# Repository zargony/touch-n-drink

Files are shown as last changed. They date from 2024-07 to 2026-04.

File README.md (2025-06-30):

# Touch 'n Drink

Touch 'n Drink is a small device that reads NFC id cards of club members of the [Aeroclub (LSC) Hamm][LSC Hamm] and allows to pay for items like cold drinks offered at the clubhouse. Purchases are forwarded to accounting so members pay via their regular monthly invoices. We're located at airfield [EDLH] in Hamm, Germany.

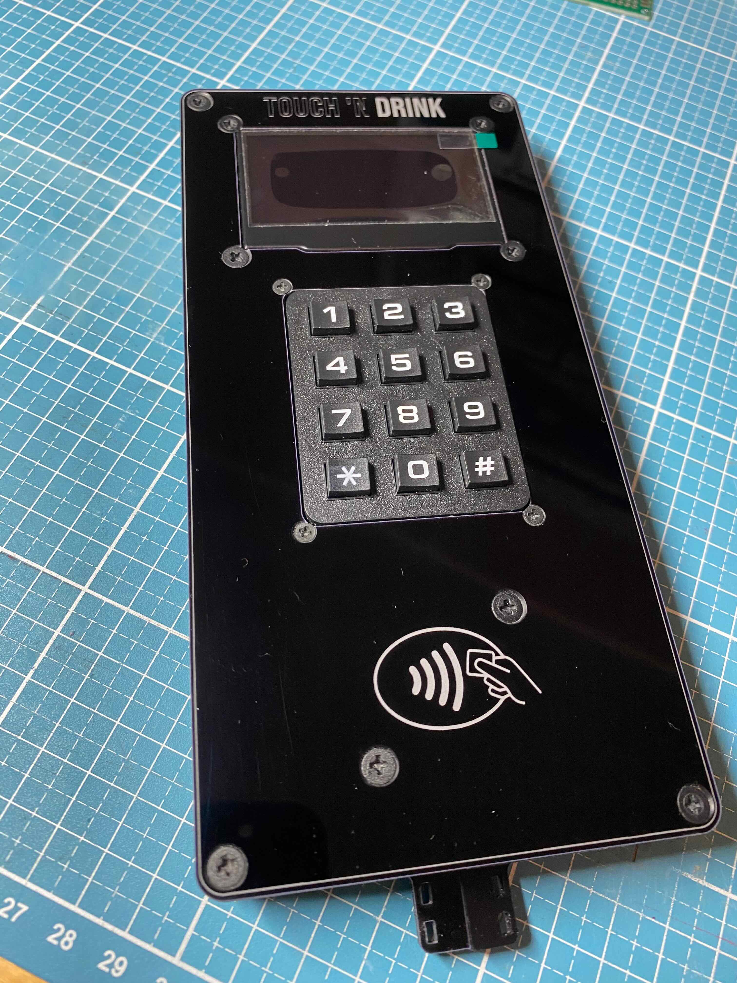
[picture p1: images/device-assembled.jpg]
Assembled device


## Features

- Fetches authorized users and list of articles for sale from [Vereinsflieger] API
- Allows users to identify with NFC tag or id card and purchase articles
- Optional event tracking using [Mixpanel] for usage analytics
- Connects to 2.4 GHz WPA2/WPA3 Wifi (IPv4, DHCP)
- Simple numeric keypad and large, bright OLED display
- Power supply using standard USB-C cable (PD not required)
- Ergonomically priced and widely available hardware components
- Magnetic wall mount

## Hardware

ESP32-C3, Keypad, OLED Display and NFC reader in a custom acrylic case. See [hardware] folder for details.

## PCB

Small custom PCB for the microcontroller and connectors to other components. Either manufactured or manually soldered to a perfboard. See [pcb] folder for details.

## Firmware

Written in [Rust]. See [firmware] folder for details.

## Contributions

If you like this project, want to use it at your club, or if you want to discuss ideas and suggestions, feel free to start a [discussion][discussions] or open an [issue][issues]. Feel free to fork this repository and base your work upon it. Please open a pull request if your changes or features are useful to a broad audience.

## License

Hardware licensed under the [CERN Open Hardware License (Strongly Reciprocal)][OHL]. Software licensed under the [European Union Public License (EUPL)][EUPL]. Unless you explicitly state otherwise, any contribution intentionally submitted for inclusion in the work by you, shall be licensed as above, without any additional terms or conditions.

[hardware]: ./hardware
[firmware]: ./firmware
[pcb]: ./pcb

[discussions]: https://github.com/zargony/touch-n-drink/discussions
[issues]: https://github.com/zargony/touch-n-drink/issues

[EDLH]: https://skyvector.com/airport/EDLH/Hamm-Lippewiesen-Airport
[EUPL]: https://interoperable-europe.ec.europa.eu/collection/eupl/eupl-text-eupl-12
[LSC Hamm]: https://flugplatz-hamm.de
[Mixpanel]: https://mixpanel.com
[OHL]: https://cern-ohl.web.cern.ch/home
[Rust]: https://www.rust-lang.org
[Vereinsflieger]: https://www.vereinsflieger.de

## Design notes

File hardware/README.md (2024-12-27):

# Touch 'n Drink Hardware

Assembled device:

Assembled device

## Electronics

Wiring of parts (PCB version):

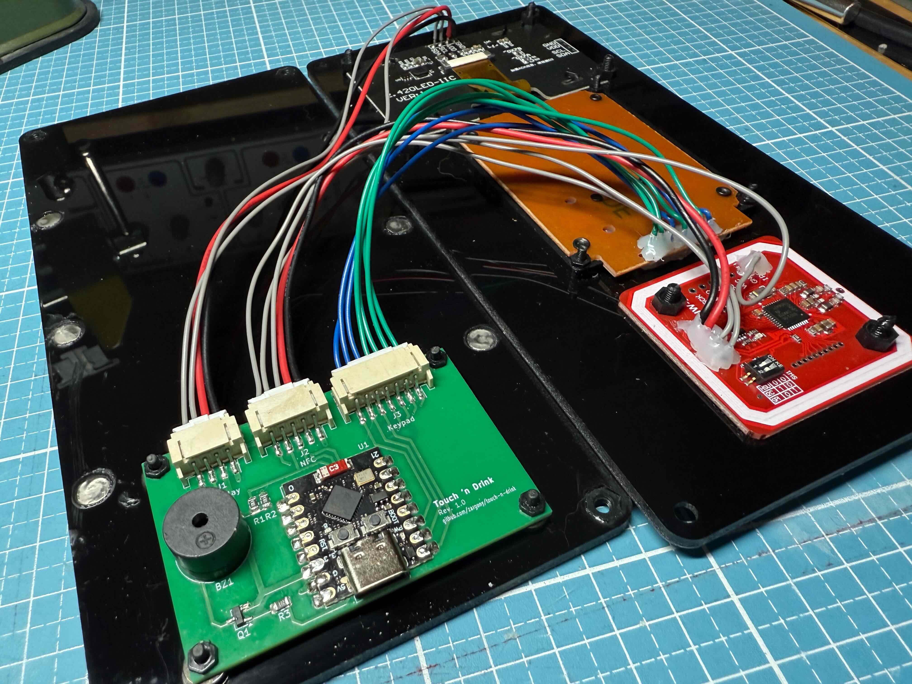
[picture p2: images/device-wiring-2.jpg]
Wiring of parts with PCB


Wiring of parts (perfboard version):

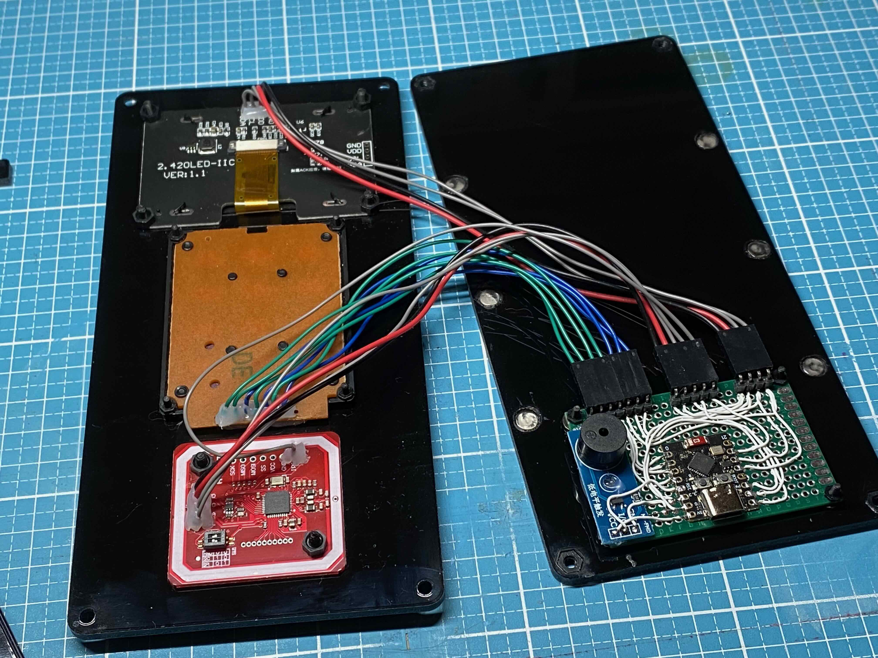
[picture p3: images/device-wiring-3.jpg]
Wiring of parts with perfboard


JST-PH connectors:

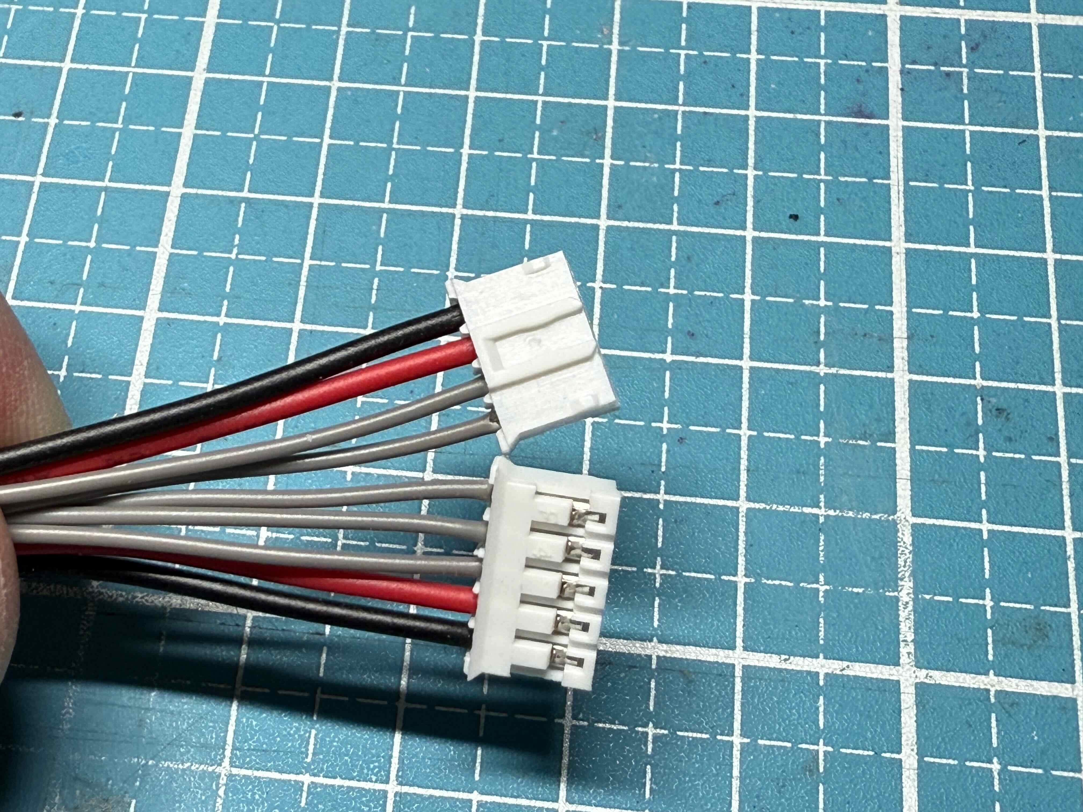
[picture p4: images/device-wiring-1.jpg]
JST-PH connectors


Prototype breadboard:

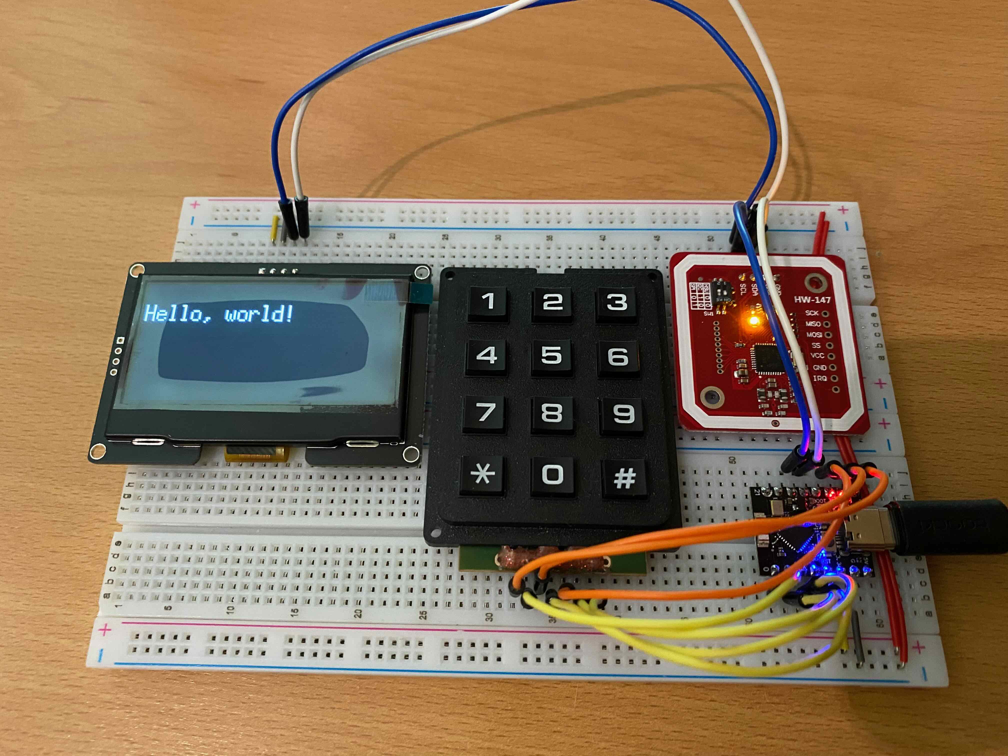
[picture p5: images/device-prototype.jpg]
Prototype breadboard


### Electronic Parts

- OLED display 2.42" I2C
  ([AliExpress](https://s.click.aliexpress.com/e/_DCysL8J)) <!-- https://www.aliexpress.com/item/1005006100836064.html -->
  ([Amazon](https://amzn.to/460m6Js)) <!-- https://www.amazon.de/module-128x64-driver-SSD1309-interface/dp/B0C745HXGB -->
  ([Model](https://grabcad.com/library/display-oled-2-42-1))
- Matrix 4x3 keypad
  ([AliExpress](https://s.click.aliexpress.com/e/_DEhcWpV)) <!-- https://www.aliexpress.com/item/1005005536316575.html -->
  ([Amazon](https://amzn.to/3Y1Twpa)) <!-- https://www.amazon.de/HALJIA-Tastatur-Membran-kompatibel-Arduino/dp/B08BBXH6NM -->
  ([Model](https://grabcad.com/library/keypad-3x4-w-pcb-1))
- PN532 NFC module v3
  ([AliExpress](https://s.click.aliexpress.com/e/_DFyKykT)) <!-- https://www.aliexpress.com/item/1005005973913526.html -->
  ([Amazon](https://amzn.to/3S3gAjo)) <!-- https://www.amazon.de/Diyeeni-Funkmodul-Reader-Android-Communication-default/dp/B07V5QDMR4 -->
  ([Model](https://grabcad.com/library/pn532-nfc-rfid-module-v3-kits-1))
- [PCB or perfboard](../pcb) with ESP32-C3

## Case

Lasercut acrylic sheets:

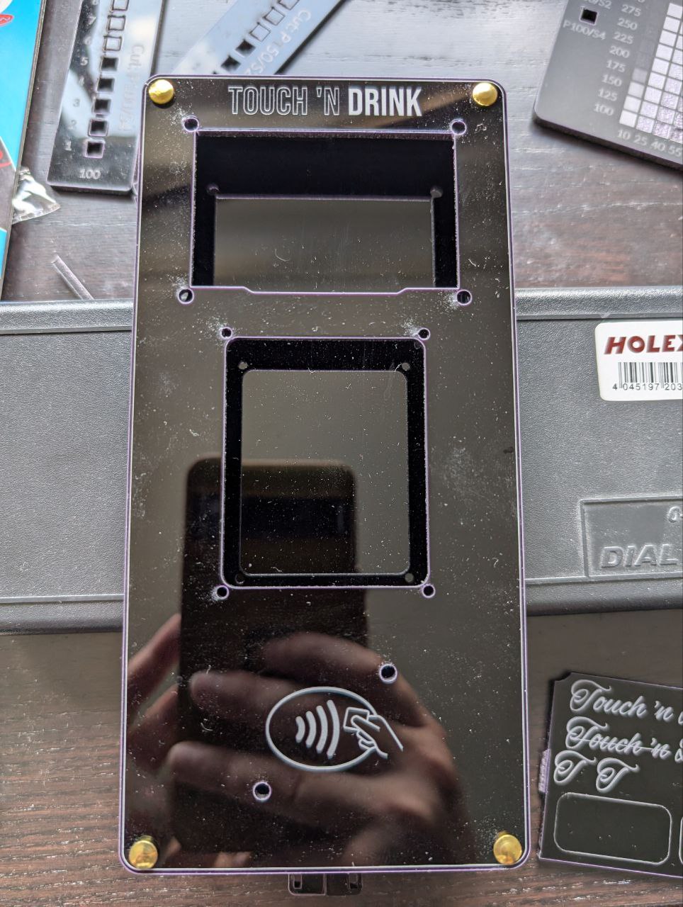
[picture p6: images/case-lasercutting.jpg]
Case lasercutting


Prototype cardboard case:

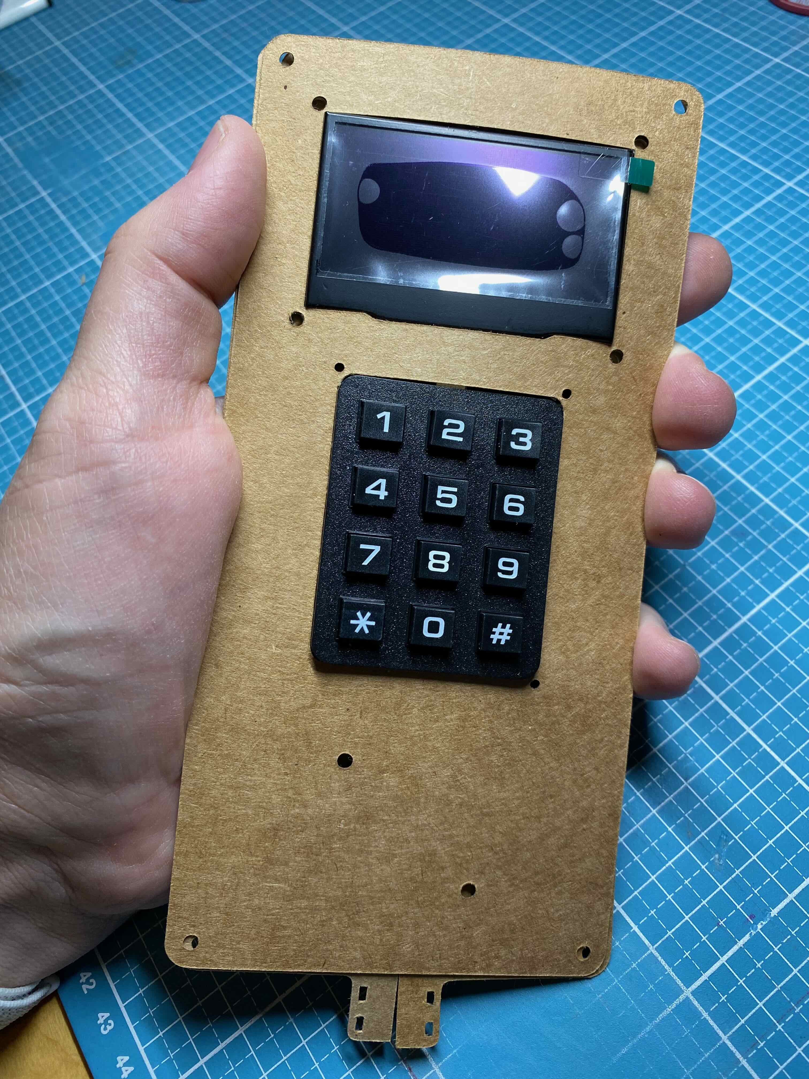
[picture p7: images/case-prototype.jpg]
Case paper prototype


Rendered CAD model:

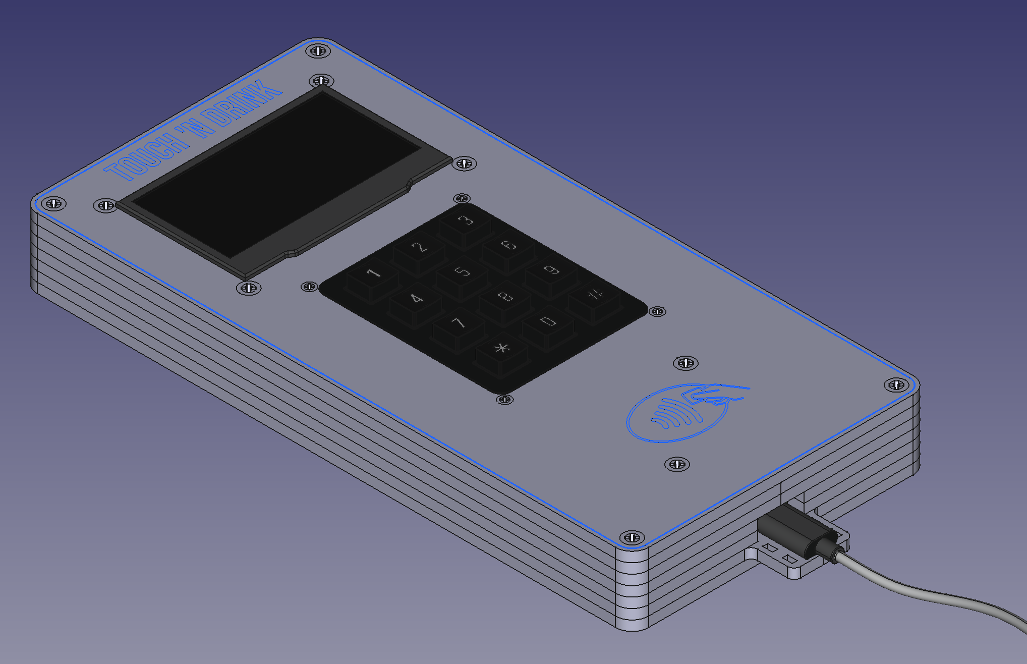
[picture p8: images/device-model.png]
Case rendered CAD model


### Hardware Parts

- Acrylic sheets, 3mm
- 8x M2x10 screws, countersunk, Nylon
  ([AliExpress](https://s.click.aliexpress.com/e/_Dnqr099)) <!-- https://www.aliexpress.com/item/1005006947644936.html -->
  ([Amazon](https://amzn.to/4bAfO4o)) <!-- https://www.amazon.de/CONPHERON-Kreuzschlitz-Senkschrauben-Kunststoff-Maschinenschrauben/dp/B09NXRQFHX -->
  ([Model](https://wiki.freecad.org/Fasteners_Workbench))
- 6x M3x10 screws, countersunk, Nylon
  ([AliExpress](https://s.click.aliexpress.com/e/_Dnqr099)) <!-- https://www.aliexpress.com/item/1005006947644936.html -->
  ([Amazon](https://amzn.to/4bAfO4o)) <!-- https://www.amazon.de/CONPHERON-Kreuzschlitz-Senkschrauben-Kunststoff-Maschinenschrauben/dp/B09NXRQFHX -->
  ([Model](https://wiki.freecad.org/Fasteners_Workbench))
- 6x M3x20 screws, countersunk, Nylon
  ([AliExpress](https://s.click.aliexpress.com/e/_Dnqr099)) <!-- https://www.aliexpress.com/item/1005006947644936.html -->
  ([Amazon](https://amzn.to/4bAfO4o)) <!-- https://www.amazon.de/CONPHERON-Kreuzschlitz-Senkschrauben-Kunststoff-Maschinenschrauben/dp/B09NXRQFHX -->
  ([Model](https://wiki.freecad.org/Fasteners_Workbench))
- 8x M2 nuts, Nylon
  ([AliExpress](https://s.click.aliexpress.com/e/_DEIu5LN)) <!-- https://www.aliexpress.com/item/1005004307521473.html -->
  ([Amazon](https://amzn.to/4603OYy)) <!-- https://www.amazon.de/CONPHERON-Kunststoff-Sechskant-Schwarz-Sechskantmutter/dp/B09N1HN8QR -->
  ([Model](https://wiki.freecad.org/Fasteners_Workbench))
- 12x M3 nuts, Nylon
  ([AliExpress](https://s.click.aliexpress.com/e/_DEIu5LN)) <!-- https://www.aliexpress.com/item/1005004307521473.html -->
  ([Amazon](https://amzn.to/4603OYy)) <!-- https://www.amazon.de/CONPHERON-Kunststoff-Sechskant-Schwarz-Sechskantmutter/dp/B09N1HN8QR -->
  ([Model](https://wiki.freecad.org/Fasteners_Workbench))
- 12x 6x3 mm Neodymium magnets (optional)
  ([AliExpress](https://s.click.aliexpress.com/e/_Dkv50zJ)) <!-- https://www.aliexpress.com/item/1005001529831924.html -->
  ([Amazon](https://amzn.to/3BZGW0k)) <!-- https://www.amazon.de/Magnete-K%C3%BChlschrankmagnete-Whiteboard-Magnettafel-Handwerk/dp/B09W8R43Q8 -->
- USB-C cable
  ([Model](https://grabcad.com/library/usb-c-with-flexed-cable-1))

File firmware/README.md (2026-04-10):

# Touch 'n Drink Firmware

Firmware images are automatically build by GitHub actions. They can be downloaded from the [releases] page and flashed to a microcontroller [from your browser][esptool-js]. The setup described below is only needed for local development.

## Requirements

For local development, you need a [Rust] toolchain. If your OS doesn't already provide it, easiest way to install and manage Rust toolchains is to use [rustup], or use the official Docker image `rust:1`.

The Rust toolchain needs to support cross-compiling to the microcontroller's target architecture. If you're using `rustup`, it'll automatically download the required components as specified in `rust-toolchain.toml`.

To flash the firmware to a device, the `espflash` and `cargo-espflash` tools can be used. They integrate well with Rust build tools and can be installed with `cargo install espflash cargo-espflash`.

## Building the Firmware

To build the firmware using the debug profile, use:

```sh
cargo xtask build
```

This will run `cargo build` with options to build a firmware image for the microcontroller. It'll then use `espflash save-image` to produce OTA and factory images (.bin files) that can be flashed to the microcontroller.

## Flash Firmware to Device

To build the firmware using the debug profile and flash it to a device, connect the device via its USB-C serial port and use:

```sh
cargo xtask run
```

This will build the firmware image and use `espflash` to flash the produced image to the microcontroller. It then resets the device and monitors any log output.

## Flash Configuration to Device

Configuration is stored in a separate flash partition and is therefore unaffected by firmware updates. As there is currently no way to change the configuration at runtime, it needs to be flashed to the device manually (once).

Create a custom configuration, e.g. `config.json`. See `config-example.json` for available settings. Before flashing, keep it small and remove all comments, either manually or by using the `jq` tool:

```sh
jq -c < config.json > config.min.json
```

Store the minimized configuration to the device's `config` partition using `espflash`:

```sh
espflash write-bin 0xd000 config.min.json
```

## Contributions

If you implement changes or features that can be useful for everyone, please fork this repository and open a pull request. Make sure to also update documentation and code comments accordingly and add a high level description of your changes to the changelog. Also make sure that all CI jobs are passing and ideally try flashing and using the firmware image artifact to verify its behaviour.

[actions]: https://github.com/zargony/touch-n-drink/actions
[releases]: https://github.com/zargony/touch-n-drink/releases

[esptool-js]: https://espressif.github.io/esptool-js
[Rust]: https://www.rust-lang.org
[rustup]: https://rustup.rs

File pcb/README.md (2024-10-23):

# Touch 'n Drink PCB

## Custom PCB

A custom PCB holds the ESP32-C3 Module, a buzzer and connectors to wire up display, keypad and NFC reader. The PCB is quite simple and easy to manufacture. Choose any manufacturer you like.

If you don't want to manufacture a PCB, it's also easily possible to wire up components on a perfboard (see below).

Soldered PCB:

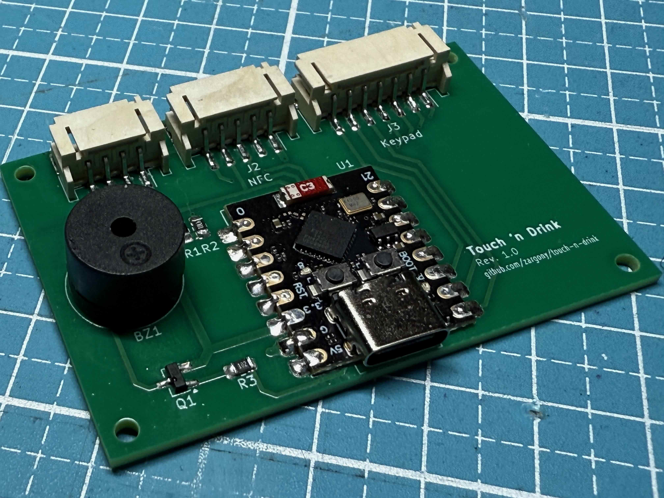
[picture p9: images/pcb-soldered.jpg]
Soldered PCB


Empty PCB:

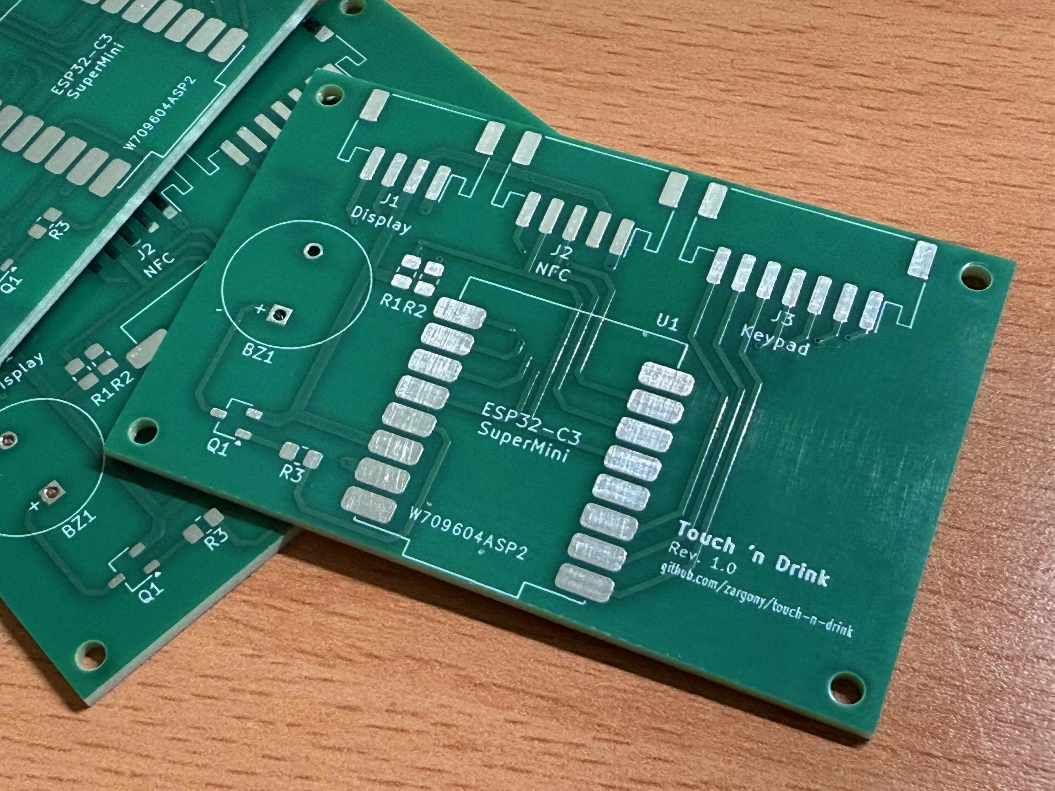
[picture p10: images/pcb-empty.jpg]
Empty PCB


Rendered PCB model:

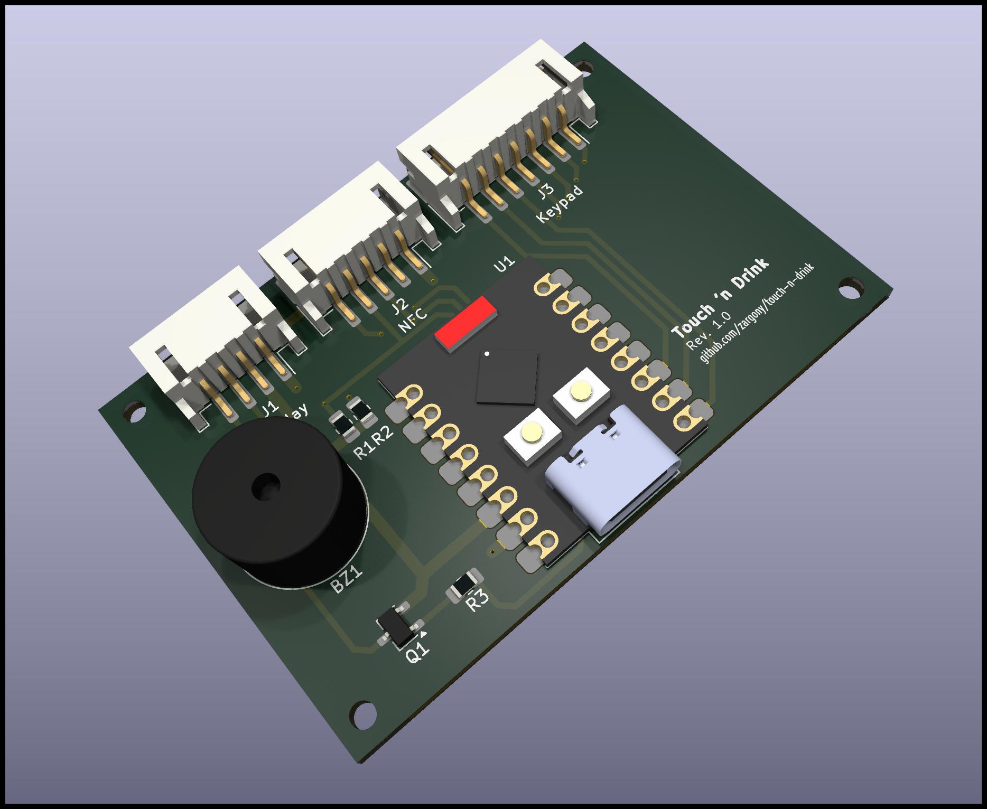
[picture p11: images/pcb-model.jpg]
Rendered PCB model


PCB Layout:

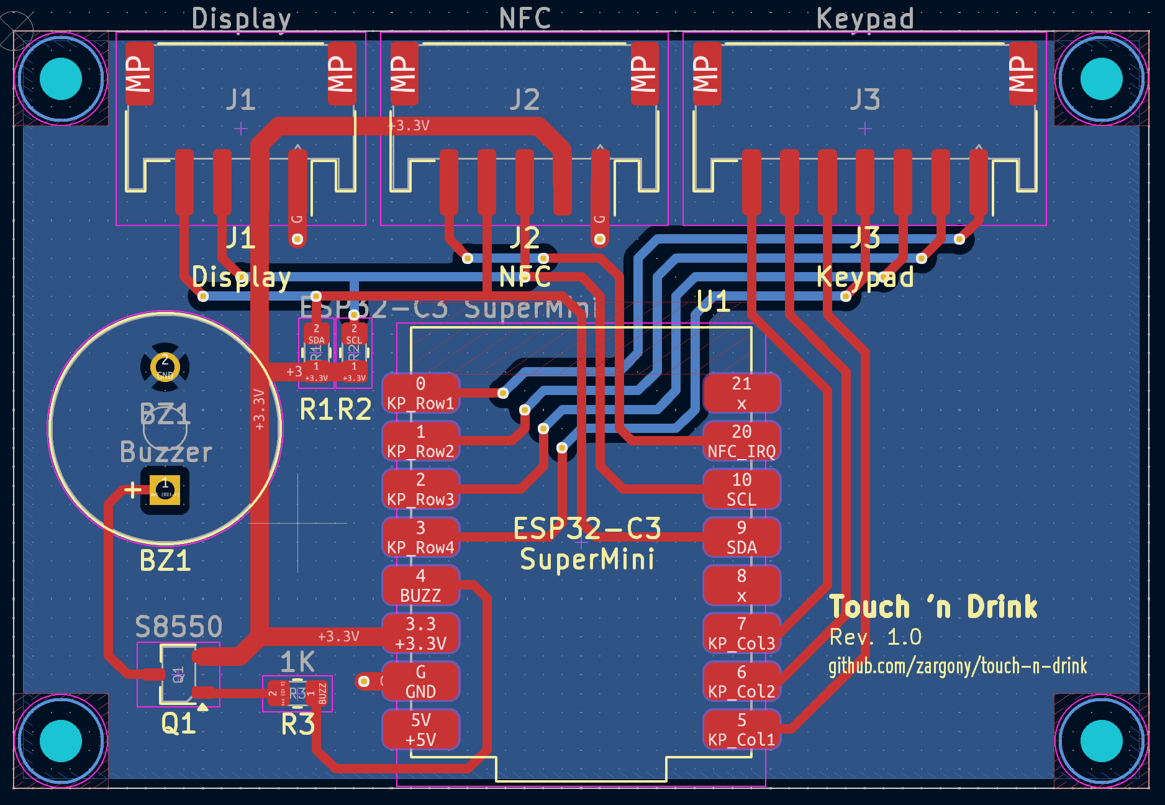
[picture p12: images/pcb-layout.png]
PCB layout


### Components

- 60x40 mm custom 2-layer PCB
- 1x ESP32-C3 SuperMini
  ([AliExpress](https://s.click.aliexpress.com/e/_DdYM4t9)) <!-- https://www.aliexpress.com/item/1005005967641936.html -->
  ([Amazon](https://amzn.to/4bCXYxz)) <!-- https://www.amazon.de/iHaospace-ESP32-C3-Mini-Entwicklungboard-ESP32-C3FN4/dp/B0D1Y5CPLX -->
  ([Model](https://grabcad.com/library/esp32c3-supermini-1))
- 1x Passive buzzer, THT, 12085
- 1x S8550, SMT, TSOT-23 (or other generic NPN transistor, BEC pin ordering)
- 1x 1k resistor, SMT, 0805
- 2x 5k resistor, SMT, 0805
- 1x 4-pin JST PH header, SMT, horizontal, S4B-PH-SM4-TB
- 1x 5-pin JST PH header, SMT, horizontal, S5B-PH-SM4-TB
- 1x 7-pin JST PH header, SMT, horizontal, S7B-PH-SM4-TB

## Perfboard (optional, instead of PCB)

Instead of manufacturing a custom PCB, you can wire up components on a 60x40 mm perfboard.

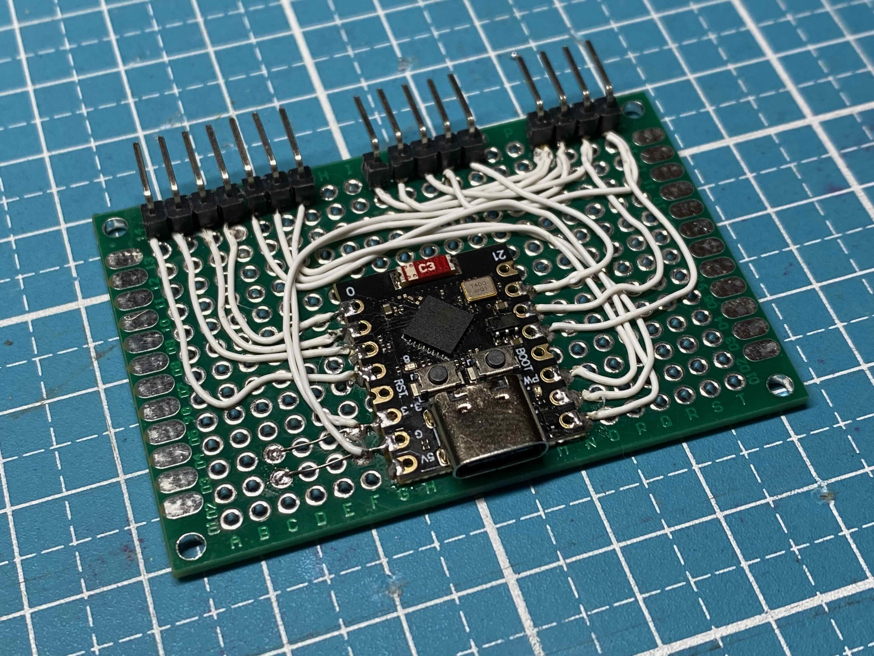
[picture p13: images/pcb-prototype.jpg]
Perfboard wiring


### Components

- Prototype PCB 60x40
  ([AliExpress](https://s.click.aliexpress.com/e/_Ddm12Wr)) <!-- https://www.aliexpress.com/item/1005006665029598.html -->
  ([Amazon](https://amzn.to/4eYnoIY)) <!-- https://www.amazon.de/Akozon-Leiterplatte-Doppelseiten-Prototyping-Universal/dp/B0B3MJ3WJM -->
  ([Model](https://grabcad.com/library/pcb-prototype-60x40-1))
- ESP32-C3 SuperMini
  ([AliExpress](https://s.click.aliexpress.com/e/_DdYM4t9)) <!-- https://www.aliexpress.com/item/1005005967641936.html -->
  ([Amazon](https://amzn.to/4bCXYxz)) <!-- https://www.amazon.de/iHaospace-ESP32-C3-Mini-Entwicklungboard-ESP32-C3FN4/dp/B0D1Y5CPLX -->
  ([Model](https://grabcad.com/library/esp32c3-supermini-1))
- Passive buzzer module, 3.3V, active low
  ([AliExpress](https://s.click.aliexpress.com/e/_Dl2FWF1)) <!-- https://www.aliexpress.com/item/1005006316591026.html -->
  ([Amazon](https://amzn.to/3Y72Ibw)) <!-- https://www.amazon.de/Jopto-Passives-niedrigstufiges-Lautsprecher-Kompatibel/dp/B096ZWCG7F -->
  ([Model](https://grabcad.com/library/buzzer-module-fc-07-1))
- Connectors for wiring to front panel (optional)
- Wires for soldering

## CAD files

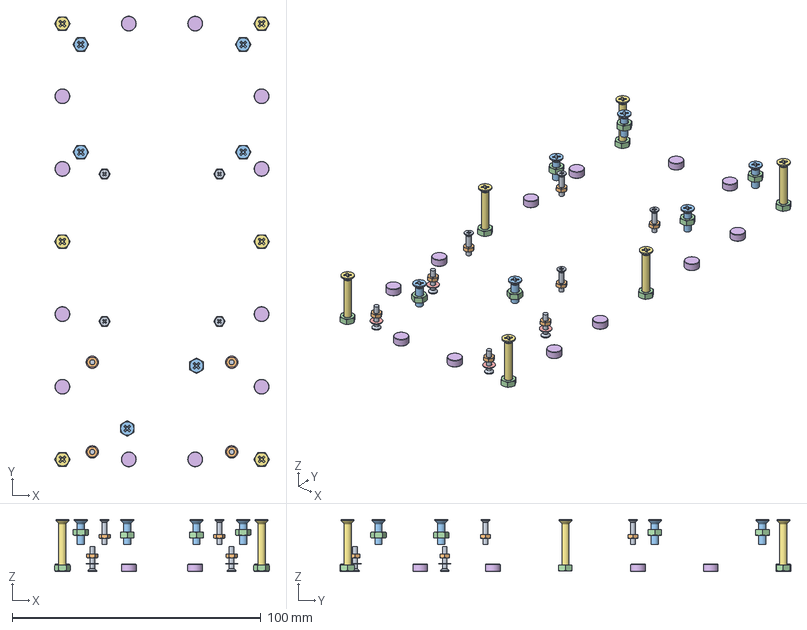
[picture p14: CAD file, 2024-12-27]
hardware/assembly.FCStd
86.4 x 181.0 x 21.0 mm
M2x10-Screw x 8
M2-Nut x 8
M3x10-Screw x 6
M3-Nut x 12
M2-Washer x 4
M3x20-Screw x 6

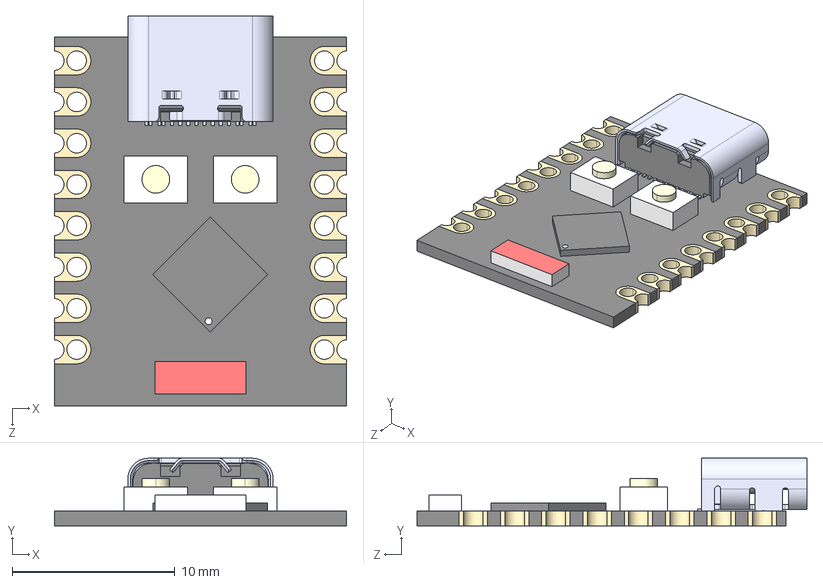
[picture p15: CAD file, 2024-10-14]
pcb/ESP32-C3_SuperMini.step
18.0 x 4.16 x 24.0 mm
Board c3mini
USB C
components (other)^ESP32-C3 SuperMini

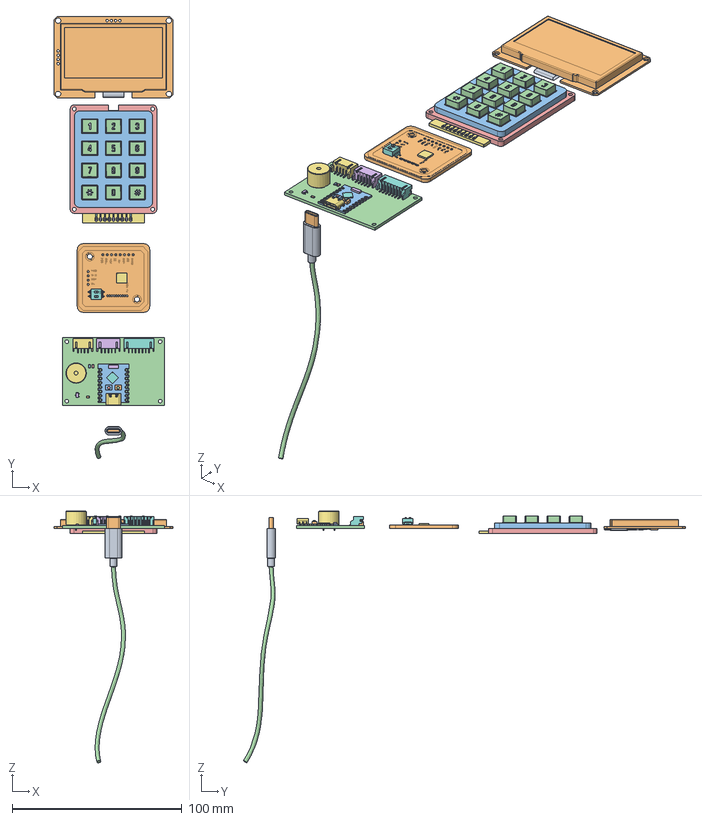
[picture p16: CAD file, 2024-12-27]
hardware/components.FCStd
70.1 x 260.3 x 148.3 mm
Body_top
KeyPad
Body_bottom
PCB_pads
PCB_base
PCBtracks
KeyPad_collor
NFC_MODULE_1
QFN40 (6x6)_1
QFN40 (6x6)_002
QFN40 (6x6)_003
QFN40 (6x6)_004
QFN40 (6x6)_005
Switch_2_1
USB-C and wire v1
USB-C and wire v002
USB-C and wire v003
USB-C and wire v004
R_0805_2012Metric
S3B-PH-SM4-TB v12
S3B-PH-SM4-TB v013
S3B-PH-SM4-TB v014
S3B-PH-SM4-TB v015
S3B-PH-SM4-TB v016
S3B-PH-SM4-TB v017
S3B-PH-SM4-TB v018
S3B-PH-SM4-TB v019
ESP32-C3 SuperMini
ESP32-C3 SuperMini001
ESP32-C3 SuperMini002
ESP32-C3 SuperMini003
ESP32-C3 SuperMini004
ESP32-C3 SuperMini005
ESP32-C3 SuperMini006
ESP32-C3 SuperMini007
ESP32-C3 SuperMini008
ESP32-C3 SuperMini009
ESP32-C3 SuperMini010
ESP32-C3 SuperMini011
ESP32-C3 SuperMini012
ESP32-C3 SuperMini013
ESP32-C3 SuperMini014
ESP32-C3 SuperMini015
ESP32-C3 SuperMini016
ESP32-C3 SuperMini017
ESP32-C3 SuperMini018
ESP32-C3 SuperMini019
ESP32-C3 SuperMini020
ESP32-C3 SuperMini021
ESP32-C3 SuperMini022
ESP32-C3 SuperMini023
ESP32-C3 SuperMini024
S3B-PH-SM4-TB v021
S3B-PH-SM4-TB v022
S3B-PH-SM4-TB v023
S3B-PH-SM4-TB v024
S3B-PH-SM4-TB v025
S3B-PH-SM4-TB v026
S3B-PH-SM4-TB v027
TSOT_23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

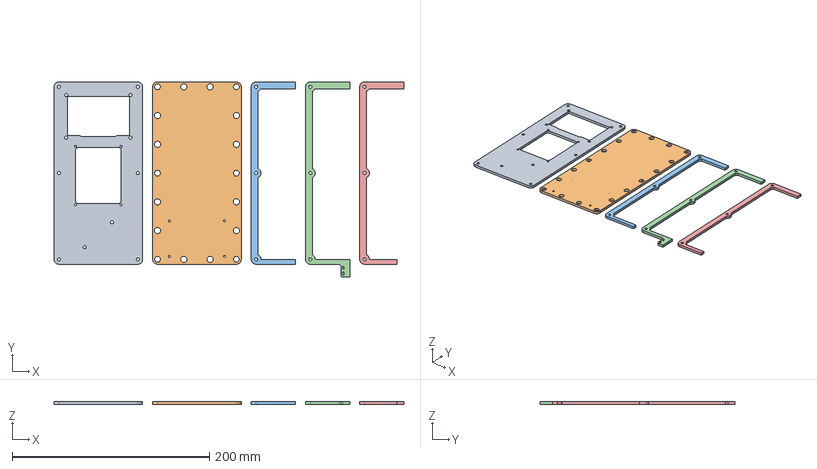
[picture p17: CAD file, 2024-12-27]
hardware/case.FCStd
355.0 x 198.0 x 3.00 mm
Front Plate Body
Back Plate Body
Spacer Full Body
Spacer Cable Body
Spacer Port Body

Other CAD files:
hardware/lasercutting.FCStd
hardware/lasercutting.dxf

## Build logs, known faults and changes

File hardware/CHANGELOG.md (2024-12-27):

# Touch 'n Drink Hardware Changelog

All notable changes to this project will be documented in this file.

The format is based on [Keep a Changelog](https://keepachangelog.com/en/1.1.0/).

## Unreleased

- Doubled number of back plate magnets for better mounting
- Additional 2 screws for more rigid left and right sides
- Added engraving of project URL and QR-Code to bottom of front plate

## Rev. 1.0 - 2024-07-23

- Case using layers of 3 mm arcylic sheets
- Front plate cutouts for display and keypad, engraved title and NFC logo
- Back plate with PCB mount and mounting magnets
- Bottom side cutout for USB-C plug with strain relief

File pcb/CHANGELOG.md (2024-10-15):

# Touch 'n Drink PCB Changelog

All notable changes to this project will be documented in this file.

The format is based on [Keep a Changelog](https://keepachangelog.com/en/1.1.0/).

## Unreleased

## Rev. 1.0 - 2024-09-14

- 60x40 mm 2-layer PCB, formfactor compatible with previous perfboard
- Pads for soldering the ESP32-C3 SuperMini module
- JST PH connectors for display, keypad and NFC
- On-board buzzer and driver (same as previous buzzer module)
- I2C pull up resistors (not needed if ESP32 pull ups are enabled)

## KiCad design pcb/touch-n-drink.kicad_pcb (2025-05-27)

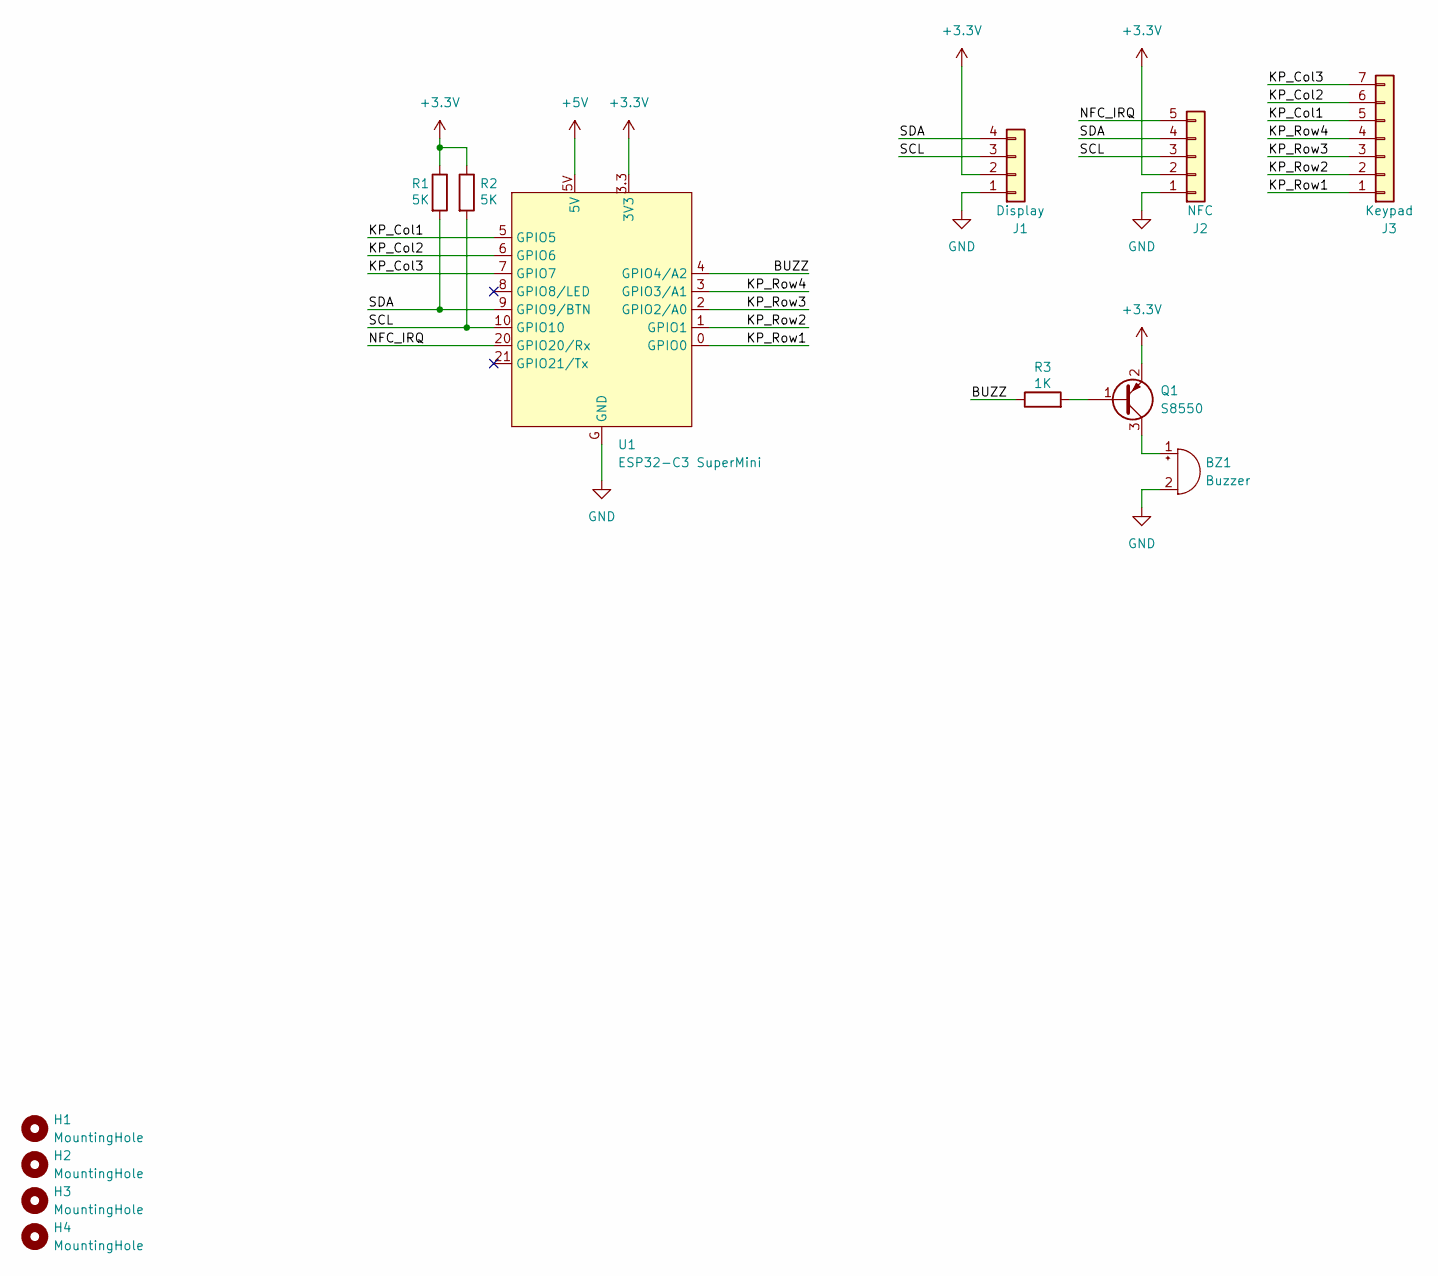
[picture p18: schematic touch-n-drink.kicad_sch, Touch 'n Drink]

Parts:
BZ1: Buzzer; MagneticBuzzer_ProSignal_ABT-410-RC
H1, H2, H3, H4: MountingHole; MountingHole_2.2mm_M2
J1: Display; JST_PH_S4B-PH-SM4-TB_1x04-1MP_P2.00mm_Horizontal
J2: NFC; JST_PH_S5B-PH-SM4-TB_1x05-1MP_P2.00mm_Horizontal
J3: Keypad; JST_PH_S7B-PH-SM4-TB_1x07-1MP_P2.00mm_Horizontal
Q1: S8550; TSOT-23
R1, R2: 5K; R_0805_2012Metric_Pad1.20x1.40mm_HandSolder
R3: 1K; R_0805_2012Metric_Pad1.20x1.40mm_HandSolder
U1: ESP32-C3 SuperMini; ESP32-C3_SuperMini

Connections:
+3.3V: J1.2, J2.2, Q1.2 (E), R1.1, R2.1, U1.3.3 (3V3)
+5V: U1.5V
/BUZZ: R3.1, U1.4 (GPIO4/A2)
/KP_Col1: J3.5, U1.5 (GPIO5)
/KP_Col2: J3.6, U1.6 (GPIO6)
/KP_Col3: J3.7, U1.7 (GPIO7)
/KP_Row1: J3.1, U1.0 (GPIO0)
/KP_Row2: J3.2, U1.1 (GPIO1)
/KP_Row3: J3.3, U1.2 (GPIO2/A0)
/KP_Row4: J3.4, U1.3 (GPIO3/A1)
/NFC_IRQ: J2.5, U1.20 (GPIO20/Rx)
/SCL: J1.3, J2.3, R2.2, U1.10 (GPIO10)
/SDA: J1.4, J2.4, R1.2, U1.9 (GPIO9/BTN)
GND: BZ1.2 (-), J1.1, J2.1, U1.G (GND)
unnamed: BZ1.1 (+), Q1.3 (C)
unnamed: Q1.1 (B), R3.2

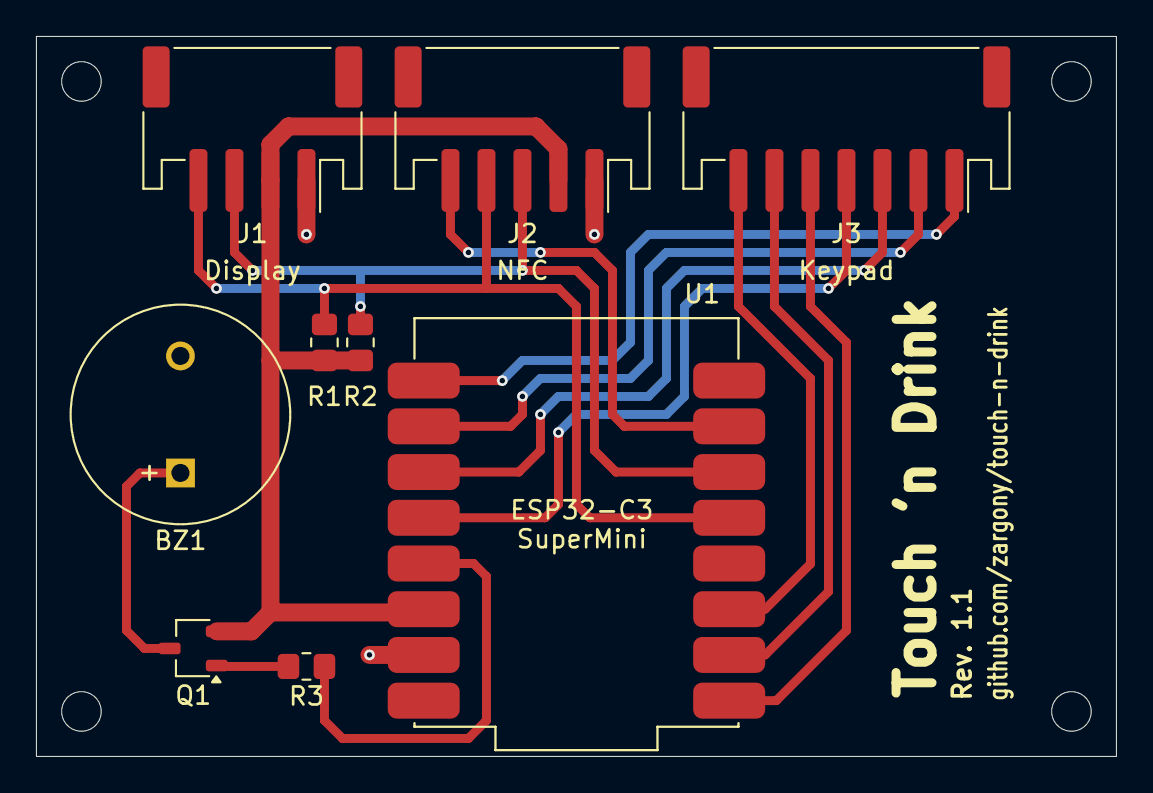
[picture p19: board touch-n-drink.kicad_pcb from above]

Board: 2 copper layers, 60.0 x 40.0 mm, 13 parts (0 on the bottom side), 15 nets.

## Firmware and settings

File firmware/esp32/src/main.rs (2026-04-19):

//! Touch 'n Drink Firmware
//!
//! Pinout ESP32-C3 Super Mini board
//!
//!                               | USB |
//! (Keypad Col1) A5/MISO/GPIO5 -  5 | 5V - 5V
//! (Keypad Col2)    MOSI/GPIO6 -  6 | G  - GND
//! (Keypad Col3)      SS/GPIO7 -  7 | 33 - 3V3
//!   (Board LED)     SDA/GPIO8 -  8 | 4  - GPIO4/A4/SCK (Buzzer)
//!     (I2C SDA)     SCL/GPIO9 -  9 | 3  - GPIO3/A3     (Keypad Row4)
//!     (I2C SCL)        GPIO10 - 10 | 2  - GPIO2/A2     (Keypad Row3)
//!     (NFC IRQ)     RX/GPIO20 - 20 | 1  - GPIO1/A1     (Keypad Row2)
//!                   TX/GPIO21 - 21 | 0  - GPIO0/A0     (Keypad Row1)
//!
//! Pinout OLED 2.42" Display
//!
//!            1   2   3   4
//!           GND VDD SCL SDA
//! GND - 1 |
//! VDD - 2 |
//! SCL - 3 |
//! SDA - 4 |
//!
//! Pinout 3x4 Matrix Keypad
//!
//!  1   2    3    4    5    6    7    8   9
//!  nc Col2 Row1 Col1 Row4 Col3 Row3 Row2 nc
//!
//! Pinout PN532 NFC Module
//!
//!             SCK MISO MOSI SS VCC GND IRQ RSTO
//!              1   2    3   4   5   6   7   8
//! GND - 1 |
//! VCC - 2 |
//! SDA - 3 |
//! SCL - 4 |
//!

#![no_std]
#![no_main]

mod buzzer;
mod config;
mod display;
mod keypad;
mod nfc;
mod pn532;
mod update;
mod wifi;

use alloc::boxed::Box;
use common::{GIT_SHA_STR, VERSION_STR};
use embassy_embedded_hal::shared_bus::asynch::i2c::I2cDevice;
use embassy_executor::Spawner;
use embassy_sync::{blocking_mutex::raw::NoopRawMutex, mutex::Mutex};
use embassy_time::{Duration, Timer};
use esp_backtrace as _;
use esp_hal::clock::CpuClock;
use esp_hal::efuse;
use esp_hal::gpio::{DriveMode, Input, InputConfig, Level, Output, OutputConfig, Pull};
use esp_hal::i2c::master::{BusTimeout, Config as I2cConfig, I2c};
use esp_hal::interrupt::software::SoftwareInterruptControl;
use esp_hal::peripherals::Peripherals;
use esp_hal::rng::Rng;
use esp_hal::rtc_cntl::{Rtc, RwdtStage};
use esp_hal::time::{Duration as EspDuration, Rate};
use esp_hal::timer::timg::TimerGroup;
use esp_println::println;
use esp_storage::FlashStorage;
use log::{debug, info, warn};

extern crate alloc;

esp_bootloader_esp_idf::esp_app_desc!();

/// Delay in seconds after which to restart on panic
#[cfg(not(debug_assertions))]
const PANIC_RESTART_DELAY: EspDuration = EspDuration::from_secs(10);
#[cfg(debug_assertions)]
const PANIC_RESTART_DELAY: EspDuration = EspDuration::from_secs(600);

/// Hardware watchdog timeout. RWDT will reset the system if not fed within this time.
const WATCHDOG_TIMEOUT: Duration = Duration::from_secs(10);

/// Custom halt function for esp-backtrace. Called after panic was handled and should halt
/// or restart the system.
#[unsafe(export_name = "custom_halt")]
unsafe fn halt() -> ! {
    unsafe {
        // System may be in any state at this time, thus everything is unsafe here. Stealing the
        // peripherals handle allows us to try to notify the user about this abnormal state and
        // restart the system. Any error should be ignored.
        let peripherals = Peripherals::steal();

        // TODO: Steal display driver and show a panic message to the user

        // Restart automatically after a delay
        println!("Restarting in {} seconds...", PANIC_RESTART_DELAY.as_secs());
        let mut rtc = Rtc::new(peripherals.LPWR);
        rtc.rwdt.set_timeout(RwdtStage::Stage0, PANIC_RESTART_DELAY);
        rtc.rwdt.unlisten();
        rtc.rwdt.enable();
        loop {
            esp_hal::riscv::asm::wfi();
        }
    }
}

#[embassy_executor::task]
async fn watchdog(mut rtc: Rtc<'static>) -> ! {
    debug!("Start watchdog task");

    // Enable watchdog
    rtc.rwdt.set_timeout(
        RwdtStage::Stage0,
        EspDuration::from_micros(WATCHDOG_TIMEOUT.as_micros()),
    );
    rtc.rwdt.listen();
    rtc.rwdt.enable();

    // Periodically feed watchdog
    let timeout = WATCHDOG_TIMEOUT / 2;
    loop {
        Timer::after(timeout).await;
        rtc.rwdt.feed();
    }
}

#[esp_rtos::main]
async fn main(spawner: Spawner) -> ! {
    let esp_config = esp_hal::Config::default().with_cpu_clock(CpuClock::max());
    let peripherals = esp_hal::init(esp_config);

    // Initialize global allocator
    esp_alloc::heap_allocator!(#[esp_hal::ram(reclaimed)] size: 64 * 1024);
    esp_alloc::heap_allocator!(size: 150 * 1024);

    // Initialize async executor
    let timg0 = TimerGroup::new(peripherals.TIMG0);
    let sw_int = SoftwareInterruptControl::new(peripherals.SW_INTERRUPT);
    esp_rtos::start(timg0.timer0, sw_int.software_interrupt0);

    // Initialize logging
    esp_println::logger::init_logger_from_env();
    info!("Touch 'n Drink v{VERSION_STR} ({GIT_SHA_STR})");

    // Initialize system devices
    let mut rng = Rng::new();
    let mut flash = FlashStorage::new(peripherals.FLASH);
    let _led = Output::new(peripherals.GPIO8, Level::High, OutputConfig::default());

    // Get device id (MAC address)
    let mut mac_address: const_hex::Buffer<6, false> = const_hex::Buffer::new();
    let device_id = mac_address.format_slice(efuse::base_mac_address().as_bytes());

    // Start feeding the watchdog
    let rtc = Rtc::new(peripherals.LPWR);
    debug!("Spawning watchdog task...");
    // Panic on failure since failing to spawn a task indicates a serious error
    spawner.spawn(watchdog(rtc).expect("Failed to spawn watchdog task"));

    // Read system configuration
    let config = config::read(&mut flash);

    // Initialize I2C controller
    let i2c_config = I2cConfig::default()
        // Standard-Mode: 100 kHz, Fast-Mode: 400 kHz
        .with_frequency(Rate::from_khz(400))
        // Reset bus after 24 bus clock cycles (60 µs) of inactivity
        .with_timeout(BusTimeout::BusCycles(24));
    let i2c = I2c::new(peripherals.I2C0, i2c_config)
        // Panic on failure since without I2C there's no reasonable way to tell the user
        .expect("I2C initialization failed")
        .with_sda(peripherals.GPIO9)
        .with_scl(peripherals.GPIO10)
        .into_async();

    // Share I2C bus. Since the mcu is single-core and I2C is not used in interrupts, I2C access
    // cannot be preempted and we can safely use a NoopMutex for shared access.
    let i2c: Mutex<NoopRawMutex, _> = Mutex::new(i2c);

    // Initialize display
    let mut display = display::Display::new(I2cDevice::new(&i2c))
        .await
        // Panic on failure since without a display there's no reasonable way to tell the user
        .expect("Display initialization failed");

    // Initialize keypad
    let keypad_input_config = InputConfig::default().with_pull(Pull::Up);
    let keypad_output_config = OutputConfig::default().with_drive_mode(DriveMode::OpenDrain);
    let mut keypad = keypad::Keypad::new(
        [
            Input::new(peripherals.GPIO5, keypad_input_config),
            Input::new(peripherals.GPIO6, keypad_input_config),
            Input::new(peripherals.GPIO7, keypad_input_config),
        ],
        [
            Output::new(peripherals.GPIO0, Level::High, keypad_output_config),
            Output::new(peripherals.GPIO1, Level::High, keypad_output_config),
            Output::new(peripherals.GPIO2, Level::High, keypad_output_config),
            Output::new(peripherals.GPIO3, Level::High, keypad_output_config),
        ],
    );

    // Initialize NFC reader
    let nfc_irq_input_config = InputConfig::default().with_pull(Pull::Up);
    let nfc_irq = Input::new(peripherals.GPIO20, nfc_irq_input_config);
    let mut nfc = nfc::Nfc::new(I2cDevice::new(&i2c), nfc_irq)
        .await
        // Panic on failure since an initialization error indicates a serious error
        .expect("NFC reader initialization failed");

    // Initialize buzzer
    let mut buzzer = buzzer::Buzzer::new(peripherals.LEDC, peripherals.GPIO4);

    // Initialize Wifi
    let wifi = wifi::Wifi::new(
        rng,
        peripherals.WIFI,
        spawner,
        config.wifi_country,
        &config.wifi_ssid,
        &config.wifi_password,
    )
    // Panic on failure since an initialization error indicates a static configuration error
    .expect("Wifi initialization failed");

    // Initialize firmware updater
    let mut updater_buffer = [0; update::BUFFER_SIZE];
    let mut updater = match update::Updater::new(&mut flash, &mut updater_buffer) {
        Ok(updater) => Some(updater),
        Err(err) => {
            warn!("Firmware updates unavailable: {err}");
            None
        }
    };

    // Run firmware
    let devices = common::Devices {
        rng: &mut rng,
        display: &mut display,
        keypad: &mut keypad,
        nfc: &mut nfc,
        buzzer: &mut buzzer,
        network: &wifi,
        updater: updater.as_mut(),
    };
    Box::pin(common::run(&config, device_id, devices)).await
}

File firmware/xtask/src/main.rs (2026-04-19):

mod chip;
use self::chip::{ALL_CHIPS, Chip, DEFAULT_CHIP};

use anyhow::{Result, anyhow};
use clap::Parser;
use clap_cargo::style::{CLAP_STYLING, ERROR, NOTE};
use sha2::{Digest, Sha256};
use std::io::{Read, Write};
use std::path::{Path, PathBuf};
use std::process::{self, Command, Stdio};
use std::{env, fs};

fn main() {
    if let Err(err) = Cli::parse().command.run() {
        eprintln!("\n{ERROR}error{ERROR:#}: {err:#}\n");
        process::exit(-1);
    }
}

#[derive(Debug, clap::Parser)]
#[command(
    bin_name = "cargo xtask",
    arg_required_else_help = true,
    styles(CLAP_STYLING)
)]
struct Cli {
    /// Path to cargo binary
    #[arg(
        long,
        env,
        hide_env_values = true,
        global = true,
        help_heading = "Global Options",
        default_value = "cargo"
    )]
    cargo: PathBuf,

    /// Path to espflash binary
    #[arg(
        long,
        env,
        hide_env_values = true,
        global = true,
        help_heading = "Global Options",
        default_value = "espflash"
    )]
    espflash: PathBuf,

    #[command(subcommand)]
    command: MainCommand,
}

fn workspace_root(cargo: &Path) -> Result<PathBuf> {
    let output = Command::new(cargo)
        .arg("locate-project")
        .arg("--workspace")
        .arg("--message-format")
        .arg("plain")
        .stdout(Stdio::piped())
        .stderr(Stdio::inherit())
        .spawn()?
        .wait_with_output()?;
    if !output.status.success() {
        return Err(anyhow!("Unable to determine cargo workspace root"));
    }
    let workspace_cargo_toml: PathBuf = String::from_utf8(output.stdout)?.into();
    let workspace_root = workspace_cargo_toml.parent().unwrap();
    Ok(workspace_root.into())
}

fn run(cmd: &mut Command) -> Result<()> {
    let status = cmd.status()?;
    if !status.success() {
        return Err(anyhow!("Command '{}' failed", cmd.get_program().display()));
    }
    Ok(())
}

#[derive(Debug, clap::Subcommand)]
enum MainCommand {
    /// Print build information
    #[command(subcommand)]
    Print(PrintCommand),

    /// Run code checks
    ///
    /// Checks code to catch common mistakes.
    Clippy(ClippyArgs),

    /// Build firmware
    ///
    /// Builds firmware for the selected chip. Produces OTA and factory .bin files and sha256 sums.
    Build(BuildArgs),

    /// Build, flash and run firmware on an attached device
    ///
    /// Builds firmware for the selected chip, flashes it to the locally attached device and
    /// monitors its log output.
    Run(RunArgs),
}

impl MainCommand {
    fn run(self) -> Result<()> {
        match self {
            Self::Print(print) => {
                print.run();
                Ok(())
            }
            Self::Clippy(clippy) => clippy.run(),
            Self::Build(build) => build.run(),
            Self::Run(run) => run.run(),
        }
    }
}

/// Print command
#[derive(Debug, clap::Subcommand)]
enum PrintCommand {
    /// Print list of firmware variants (chips) available for building
    Chips,

    /// Print package to use for the given firmware variant (chip)
    Package {
        #[arg(long, value_enum)]
        chip: Chip<'static>,
    },

    /// Print target triple to use for the given firmware variant (chip)
    Target {
        #[arg(long, value_enum)]
        chip: Chip<'static>,
    },
}

impl PrintCommand {
    fn run(self) {
        match self {
            Self::Chips => {
                for chip in ALL_CHIPS {
                    println!("{}", chip.name);
                }
            }
            Self::Package { chip } => println!("{}", chip.package),
            Self::Target { chip } => println!("{}", chip.target),
        }
    }
}

/// Clippy command arguments
#[derive(Debug, clap::Args)]
struct ClippyArgs {
    /// The firmware variant (chip) to check
    #[arg(long, value_enum, default_value = DEFAULT_CHIP)]
    chip: Chip<'static>,

    #[arg(from_global)]
    cargo: PathBuf,

    /// Additional arguments forwarded to `cargo clippy`
    #[arg(trailing_var_arg = true, allow_hyphen_values = true)]
    args: Vec<String>,
}

impl ClippyArgs {
    fn run(self) -> Result<()> {
        let chip = self.chip.name;

        // Cargo clippy
        println!("       {NOTE}XTask{NOTE:#} Running code checks for firmware variant `{chip}`");
        run(Command::new(&self.cargo)
            .current_dir(workspace_root(&self.cargo)?)
            .arg("clippy")
            .args(self.chip.cargo_args())
            .args(&self.args))?;

        Ok(())
    }
}

/// Build command arguments
#[derive(Debug, clap::Args)]
struct BuildArgs {
    /// The firmware variant (chip) to build
    #[arg(long, value_enum, default_value = DEFAULT_CHIP)]
    chip: Chip<'static>,

    #[arg(from_global)]
    cargo: PathBuf,
    #[arg(from_global)]
    espflash: PathBuf,

    /// Additional arguments forwarded to `cargo build`
    #[arg(trailing_var_arg = true, allow_hyphen_values = true)]
    args: Vec<String>,
}

fn generate_sha256(path: &Path) -> Result<()> {
    let mut file = fs::File::open(path)?;
    let mut hasher = Sha256::new();
    let mut buffer = [0; 8192];
    let digest = loop {
        match file.read(&mut buffer)? {
            0 => break hasher.finalize(),
            len => hasher.update(&buffer[..len]),
        }
    };
    let mut file = fs::File::create(path.with_extension("sha256"))?;
    for b in digest {
        write!(file, "{b:02x}")?;
    }
    writeln!(file, "  {}", path.file_name().unwrap().display())?;
    Ok(())
}
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

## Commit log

2024-07-09 Add 3d models of hardware components
    [components.FCStd]
2024-07-09 Add preliminary case designs
    [case.FCStd]
2024-07-09 Add case and components assembly
    [assembly.FCStd]
2024-07-10 Add case fasteners and mounting magnets
    [assembly.FCStd, case.FCStd]
2024-07-10 Add SSD1309 display driver with dummy hello screen
2024-07-11 Switch to more actively maintained SSD1306 driver which is SSD1309 compatible
2024-07-11 Use 10mm screws and remove washers from assembly
    [assembly.FCStd, case.FCStd]
2024-07-12 Improve side spacer width and PCB placement
    [assembly.FCStd, case.FCStd]
2024-07-12 Improve case cable hole and add cable strain release
    [assembly.FCStd, case.FCStd]
2024-07-13 Update some mounting holes after measuring received hardware parts
    [assembly.FCStd, case.FCStd]
2024-07-14 Adjust back plate mounting holes
    [assembly.FCStd, case.FCStd]
2024-07-14 Switch from SPI to I2C for display and upcoming devices
2024-07-15 Add matrix keypad driver
2024-07-15 Add images of prototype
2024-07-19 Add front plate engraving
    [case.FCStd]
2024-07-19 Add design and output files for lasercutting
    [lasercutting.FCStd, lasercutting.dxf]
2024-07-23 Update front plate engravings
    [case.FCStd, lasercutting.FCStd, lasercutting.dxf]
2024-07-25 Rename cad model screenshot
2024-08-07 Switch to new VScode crates extension
2024-08-10 Fix and describe log filter configuration
2024-08-10 Remove prefix from error types and add better error descriptions
    [display.rs]
2024-08-10 Panic on early initialization errors
    [main.rs]
2024-08-10 Derive Clone and Debug and rename variants of keypad driver error
2024-08-10 Show git short sha on splash screen
    [display.rs]
2024-08-10 Log driver initialization
2024-08-17 Add more screens and test user flow
2024-08-17 Implement main user interface flow
2024-08-18 Log start and success of device initialization
2024-08-19 Use open-drain outputs for keypad
    Required to prevent short circuits between high and low outputs when multiple keys are pressed. Unfortunately open-drain output pins are not covered by embedded-hal, so the keypad driver now depends on esp-hal.
    [main.rs]
2024-08-19 Use shared I2C bus
2024-08-19 Add image of assembled device
2024-08-19 Add GPIO wiring to main module comments
2024-08-22 Initialize ESP32 clocks to boot default rather than max performance
2024-08-22 Make I2C bus sharing construction more obvious
2024-08-26 Make NFC error type non-exhaustive
    [nfc.rs]
2024-08-26 Add passive buzzer driver
    [buzzer.rs, main.rs]
2024-08-26 Improve logging of user interface main flow
2024-08-27 Switch to async I2C
2024-08-27 Turn screen back on when a key is pressed while power saving
2024-08-27 Refactor power saving. Refresh screen only when leaving power saving
2024-08-30 Switch to ssd1306 driver 0.9.0 with embedded-hal 1.0 and async support
2024-08-31 Refactor custom pn532 driver
2024-09-03 Add images of PCB and component wiring
2024-09-04 Fix Keypad wiring typo
    [main.rs]
2024-09-04 Switch to I2C Fast-Mode
2024-09-04 Remove obsolete comment about async I2C
2024-09-09 Remove unneeded async from buzzer drive function
    [buzzer.rs]
2024-09-09 Switch clippy to pedantic and fix some warnings
    [pn532.rs]
2024-09-14 Warn when reading non-ready frame from PN532
2024-09-23 Slightly refactor ui flow
2024-09-26 Provide static TCP sockets so they aren't bound to the Wifi controller's lifetime
2024-09-27 Add HTTP(S) client with JSON (de)serialization
2024-10-01 Provide convenient network type aliases, static DNS socket and TCP client
2024-10-02 More relaxed lifetimes of DNS socket and TCP client
2024-10-04 Pass HID resources as references to UI flow
2024-10-14 Create PCB design
    [ESP32-C3_SuperMini.step, pcb.kicad_pcb, pcb.kicad_sch]
2024-10-14 Update CAD drawings with new PCB model
    [assembly.FCStd, case.FCStd, components.FCStd]
2024-10-14 Add PCB information, rearrange hardware README
2024-10-15 Add PCB changelog
2024-10-15 Move PCB design to a separate folder
    [ESP32-C3_SuperMini.step, touch-n-drink.kicad_pcb, touch-n-drink.kicad_sch]
2024-10-17 Add GitHub URL and QR to front plate engravings, avoid duplicate vector paths
2024-10-17 Add hardware (case) changelog
2024-10-17 Add missing neodymium magnets to hardware parts list
2024-10-17 Add more screws and magnets to case for more rigid sides and better adhesion
    [assembly.FCStd, case.FCStd, lasercutting.FCStd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]
2024-10-23 Add images of PCB
2024-10-25 Use separate config data partition, also prepare OTA partitions
    [partitions.csv]
2024-10-25 Improve buzzer sounds, add deny tone
    [buzzer.rs]
2024-10-27 I2C transactions were fixed in esp-hal 0.21, remove workaround for PN532 reading
    [pn532.rs]
2024-10-27 Better handling of startup initialization and error
    [main.rs]
2024-10-27 Rearrange flash partitions to increase app space from 1M to 1.3M
    [partitions.csv]
2024-10-27 Improve visibility of user flow errors in logs
    [main.rs]
2024-10-29 Extract current time from HTTP responses and keep track of it
2024-12-04 Accept any timezone when setting current time
2024-12-20 Enhance global error type to optionally provide the user whose actions caused the error
    [main.rs]
2024-12-24 Re-save CAD files using FreeCAD 1.0.0
    [assembly.FCStd, case.FCStd, components.FCStd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]
2025-01-24 Increase NFC buffer size. Fixes "buffer too small" errors with some cards
    [pn532.rs]
2025-02-05 Fix max NFC response length
    [nfc.rs, pn532.rs]
2025-05-27 Update PCB project to KiCad 9.0
    [touch-n-drink.kicad_pcb, touch-n-drink.kicad_sch]
2025-05-27 Increase font size of project name on silkscreen
    [touch-n-drink.kicad_pcb]
2025-09-14 Fix clippy::uninlined-format-args warning introduced in Rust 1.88
    [buzzer.rs, main.rs, nfc.rs]
2025-09-14 Ignore bad response frame errors while waiting to detect NFC target
    [nfc.rs]
2025-09-16 Flag config partition as read-only
    [partitions.csv]
2025-09-16 Adjust partition scheme for larger app image and optional persistent data
    [partitions.csv]
2026-02-27 Really turn off LEDC driving when not needed
2026-03-10 Replace custom JSON (de)serialization with serde and serde_json
    [main.rs, nfc.rs]
2026-03-11 Replace u8g2 font renderer with embedded-graphics
    [display.rs]
2026-03-12 Use default size for TCP socket tx/rx buffers
2026-03-15 Update partition table layout and config partition type
    [partitions.csv]
2026-03-19 Properly parse and filter article, sale and user dates
2026-03-27 Switch to embassy Duration type in main
2026-03-28 Remove user interface related delays from buzzer
    [buzzer.rs]
2026-03-31 Refactor extracting current time from Vereinsflieger API
2026-04-08 Split firmware into multiple crates
    [partitions.csv]
2026-04-08 Move buzzer methods to buzzer interface trait
    [buzzer.rs, main.rs]
2026-04-15 Replace xtask xshell with std::process and std::fs
    Fixes crash and input-handling of long-running `cargo xtask run` because xshell always closes stdin
    [main.rs]
2026-04-19 Remove unneeded dependencies from esp32 crate
2026-04-19 Add features for ESP32 hardware variants
2026-04-19 Add xtask options for ESP32 hardware variants
